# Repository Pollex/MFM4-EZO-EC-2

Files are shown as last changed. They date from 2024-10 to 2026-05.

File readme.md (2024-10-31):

# MFM Atlas Scientific Module x2

This sensor module carries a Atlas-Scientific EZO-EC board and isolates and multiplexes the signal line to two SMA connectors for probes.

This sensor module contains a USB-C port for easier configuration and calibration of the different probes. This also allows the module to be used standalone in an ESD protected environment.

## Hardware

A single MFM V4 has two sensor module slots with about 9mm clearance between slot 1 and 2.

### Parts

Most if not all parts in kicad have a datasheet attached to them. Select the part in the Schematic Editor and press the 'd' key.

## Firmware

To be designed

## Configuration interface

To be designed

# RIOT OS
Clone riot os 2024.07 and apply patch 001

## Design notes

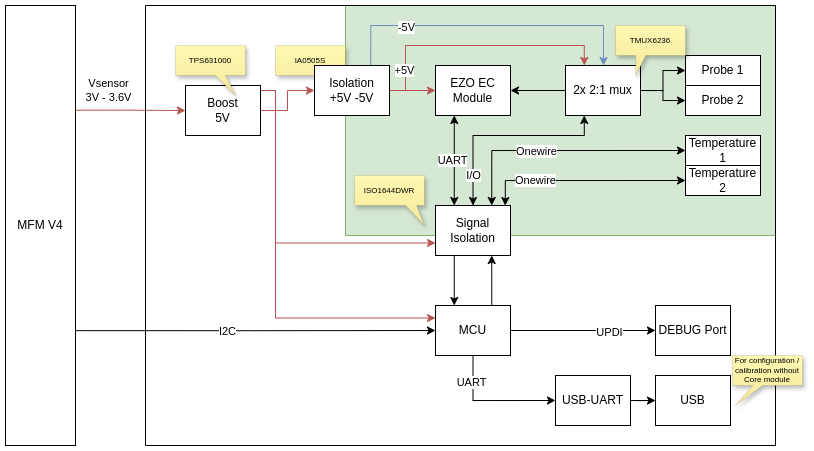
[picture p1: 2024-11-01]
docs/MFM-EC-Diagram.png

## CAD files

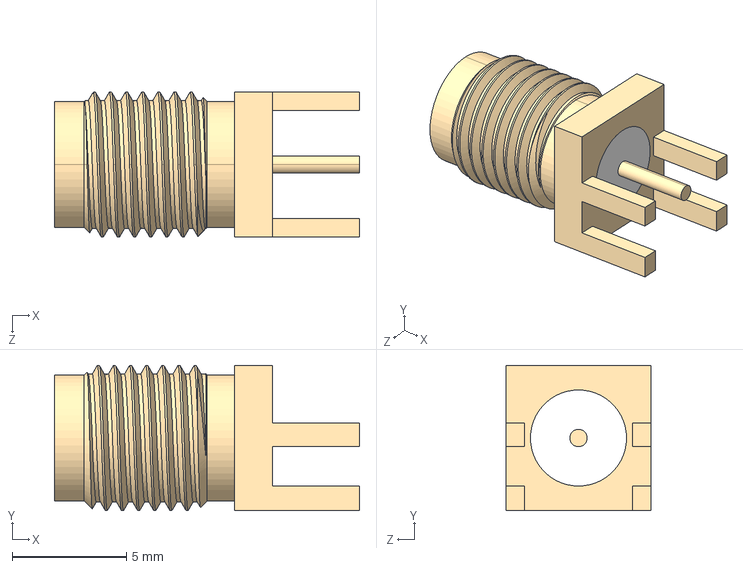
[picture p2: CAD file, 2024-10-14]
hardware/CON-SMA-EDGE-S/CON-SMA-EDGE-S.step
13.3 x 6.35 x 6.35 mm

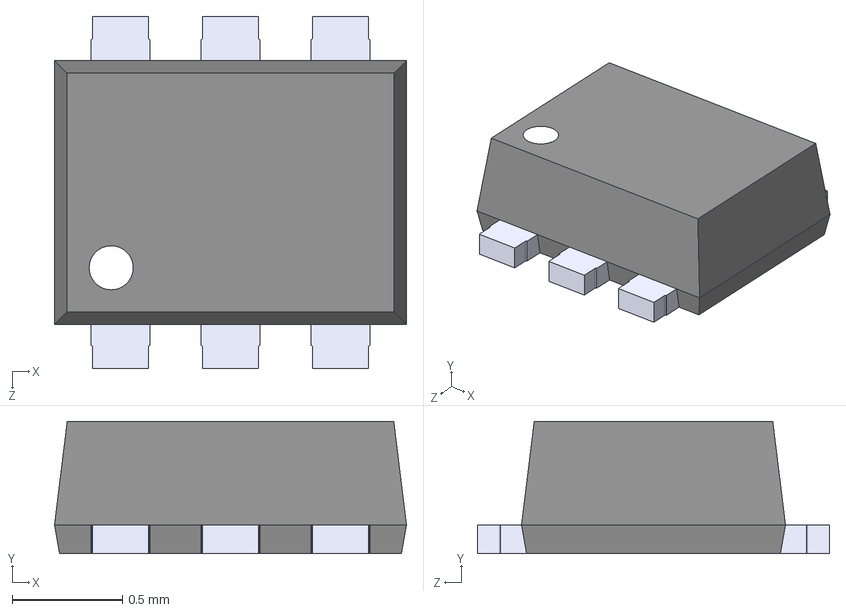
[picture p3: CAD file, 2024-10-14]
hardware/USBLC6-2P6/USBLC6-2P6.step
1.60 x 0.6 x 1.60 mm

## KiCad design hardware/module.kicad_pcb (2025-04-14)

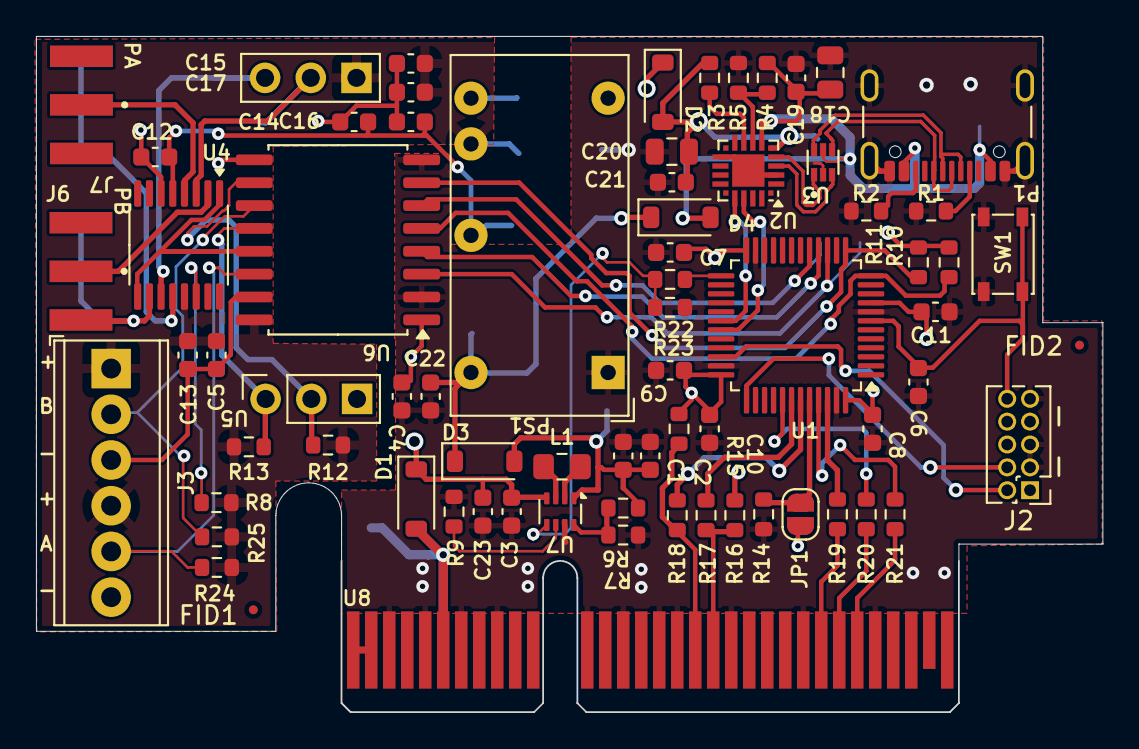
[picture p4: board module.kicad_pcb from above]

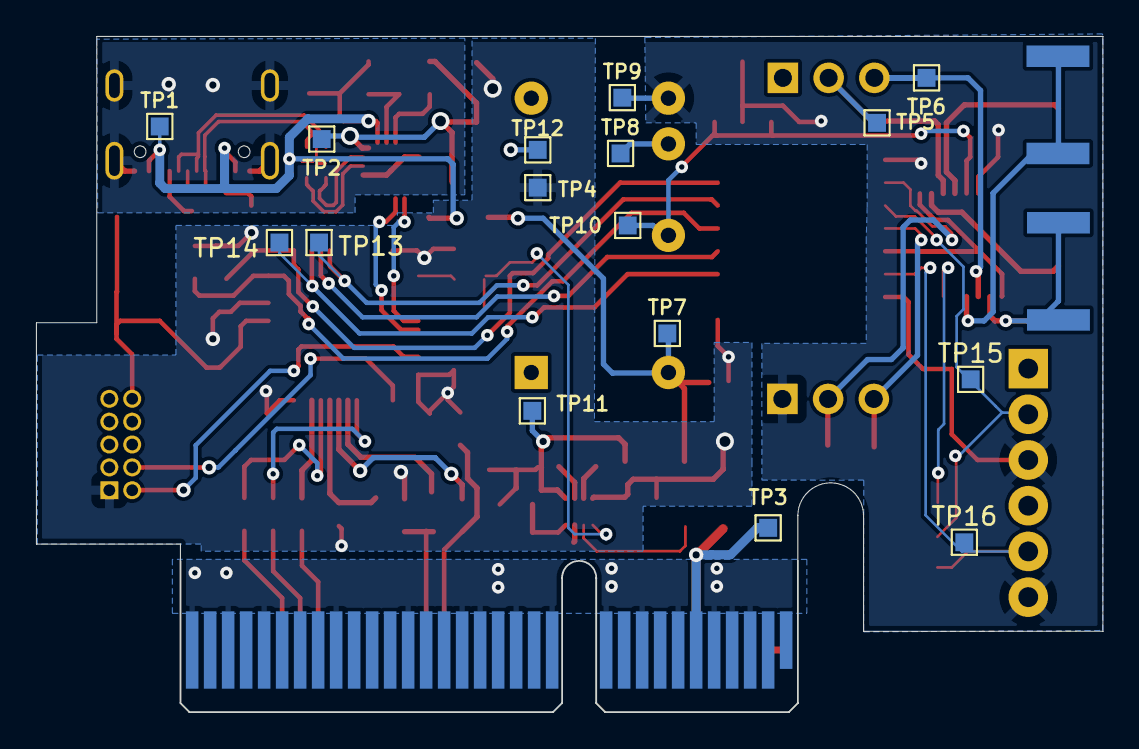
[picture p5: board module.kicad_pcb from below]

Board: 2 copper layers, 59.2 x 37.5 mm, 87 parts (16 on the bottom side), 59 nets.

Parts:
C1, C11, C16, C17, C19, C21: 4u7; C_0603_1608Metric
C2, C22, C23: 10u; C_0603_1608Metric
C3: 22u; C_0603_1608Metric
C4, C5, C6, C7, C8, C9, C10, C12, C13, C14, C15: 100n; C_0603_1608Metric
C18, C20: 47u; C_0805_2012Metric
D1, D2, D3, D4: MBR0520LT1G; D_SOD-123
FID1, FID2: Fiducial; Fiducial_0.5mm_Mask1mm
J2: GPHD-2X05; PinHeader_2x05_P1.27mm_Vertical
J3: 1725698; TerminalBlock_Phoenix_MPT-0,5-6-2.54_1x06_P2.54mm_Horizontal
J6, J7: CON-SMA-EDGE-S; RFSOLUTIONS_CON-SMA-EDGE-S
JP1: BOOT; SolderJumper-2_P1.3mm_Open_RoundedPad1.0x1.5mm
L1: LPWI201208S1R0T; L_0805_2012Metric_Pad1.15x1.40mm_HandSolder
P1: USB4105-GF-A; USB_C_Receptacle_GCT_USB4105-xx-A_16P_TopMnt_Horizontal
PS1: IA0505D; Converter_DCDC_XP_POWER-IAxxxxD_THT
R1, R2, R24, R25: 5k2; R_0603_1608Metric
R3, R14: 1k; R_0603_1608Metric
R4: 22k1; R_0603_1608Metric
R5: 47k5; R_0603_1608Metric
R6: 806k; R_0603_1608Metric
R7: 91k; R_0603_1608Metric
R8, R9, R23: 10k; R_0603_1608Metric
R10, R11, R12, R13: 3k; R_0603_1608Metric
R15, R16: 2K2; R_0603_1608Metric
R17, R18, R19, R20, R21, R22: 0R; R_0603_1608Metric
SW1: PTS810SJG250SMTRLFS; SW_SPST_PTS810
TP1, TP2, TP3, TP4, TP5, TP6, TP7, TP8, TP9, TP10, TP11, TP12, TP13, TP14, TP15, TP16: TestPoint; TestPoint_Pad_1.0x1.0mm
U1: STM32L010C6T6; LQFP-48_7x7mm_P0.5mm
U2: CP2102N-A02-GQFN20; SiliconLabs_QFN-20-1EP_3x3mm_P0.5mm_EP1.8x1.8mm
U3: USBLC6-2P6; SOT50P160X60-6N
U4: TMUX6236PWR; TSSOP-16_4.4x5mm_P0.65mm
U5: EZO-EC™; EZO_EZ
U6: ISO1644DWR; SOIC-16W_7.5x10.3mm_P1.27mm
U7: TPS631000DRLR; SOT-583-8
U8: PCIEx4; BUS_PCIexpress_x4

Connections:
3V3: C3.1, C4.1, C7.1, C8.1, C9.1, C10.1, C11.1, C23.1, D1.1 (K), D2.1 (K), J2.1, JP1.2 (B), R10.2, R11.2, R15.1, R16.1, TP4.1, U1.9 (VDDA), U1.24 (VDD), U1.36 (VDD), U1.48 (VDD), U6.1 (VCC1), U7.4 (Vin)
+5V: C1.1, C2.1, D3.2 (A), R6.2, TP11.1, U7.1 (Vout)
+5V_ISO: C5.1, C13.1, C15.1, C17.1, J3.1, J3.4, PS1.5 (+Vout), R8.2, R12.1, R13.1, R24.2, R25.2, TP8.1, U4.13 (VDD), U5.6 (VCC), U6.16 (VCC2)
-5V_ISO: C12.1, C14.2, C16.2, PS1.4 (-Vout), TP10.1, U4.5 (VSS)
/BOOST_EN: R22.1, R23.1, U7.5 (EN)
/BOOT: JP1.1 (A), R14.2, U1.44 (BOOT0)
/CP_N: U2.5 (D-), U3.1
/CP_P: U2.4 (D+), U3.3
/DQ_TEMP_A: TP14.1, U1.15 (PA5), U6.3 (SDA1)
/DQ_TEMP_A_ISO: J3.5, R24.1, TP16.1, U6.14 (SDA2)
/DQ_TEMP_B: TP13.1, U1.17 (PA7), U6.6 (SCL1)
/DQ_TEMP_B_ISO: J3.2, R25.1, TP15.1, U6.11 (SCL2)
/I2C_SCL: R16.2, R17.1, U8.B19
/I2C_SDA: R15.2, R18.1, U8.B18
/LPUART1_RX: R11.1, U1.13 (PA3), U6.7 (OUT)
/LPUART1_TX: R10.1, U1.12 (PA2), U6.5 (INB)
/MOD_ID1: R19.1, U8.B25
/MOD_ID2: R20.1, U8.B26
/MOD_ID3: R21.1, U8.B27
/NRST: C6.1, J2.10, SW1.2 (B), U1.7 (NRST)
/PRB_SEL: U4.1 (SEL1), U4.9 (SEL2), U6.13 (OUTA)
/PRB_SEL_MCU: U1.16 (PA6), U6.4 (INA)
/SWCLK: J2.4, U1.37 (PA14)
/SWDIO: J2.2, U1.34 (PA13)
/SensorConnector/VBUS: U8.A1, U8.A2, U8.B1, U8.B2
/SensorConnector/VREF: U8.A8, U8.B8
/UART2_RX: U1.31 (PA10), U2.18 (TXD)
/UART2_TX: U1.30 (PA9), U2.17 (RXD)
/USB_N: P1.A7 (D-), P1.B7 (D-), U3.6
/USB_P: P1.A6 (D+), P1.B6 (D+), U3.4
CP2102_3V3: C20.1, C21.1, D2.2 (A), R3.2, TP2.1, U2.6 (VDD)
GND: C1.2, C2.2, C3.2, C4.2, C6.2, C7.2, C8.2, C9.2, C10.2, C11.2, C18.2, C19.2, C20.2, C21.2, C22.2, C23.2, J2.3, J2.5, J2.9, P1.A1 (GND), P1.A12 (GND), P1.B1 (GND), P1.B12 (GND), P1.S1 (SHIELD), PS1.1 (-Vin), R1.2, R2.2, R5.1, R7.1, R9.2, R14.1, R23.2, SW1.1 (A), TP12.1, U1.8 (VSSA), U1.23 (VSS), U1.35 (VSS), U1.47 (VSS), U2.3 (GND), U2.12 (GND), U2.21 (GND), U3.2, U6.2 (GND1), U6.8 (GND1), U7.7 (GND), U8.A3, U8.A4, U8.A5, U8.A7, U8.A9, U8.A11, U8.A12, U8.A14, U8.A16, U8.A17, U8.A18, U8.A19, U8.A20, U8.A24, U8.A26, U8.A28, U8.A30, U8.A32, U8.B3, U8.B5, U8.B7, U8.B9, U8.B12, U8.B14, U8.B16, U8.B17, U8.B20, U8.B24, U8.B28
GND_ISO: C5.2, C12.2, C13.2, C14.1, C15.2, C16.1, C17.2, J3.3, J3.6, PS1.6 (0V), TP9.1, U4.6 (GND), U5.3 (GND), U6.9 (GND2), U6.15 (GND2)
unnamed: C22.1, D3.1 (K), D4.1 (K), PS1.3 (+Vin), TP7.1
unnamed: P1.A5 (CC), R1.1
unnamed: P1.B5 (VCONN), R2.1
unnamed: R20.2, U1.41 (PB5)
unnamed: R17.2, U1.42 (PB6)
unnamed: R18.2, U1.43 (PB7)
unnamed: R21.2, U1.45 (PB8)
unnamed: R19.2, U1.46 (PB9)
unnamed: R22.2, U1.25 (PB12)
unnamed: R4.1, R5.2, U2.8 (VBUS)
unnamed: R3.1, U2.9 (~RST)
unnamed: TP5.1, U4.3 (D1), U5.5 (PRB)
unnamed: TP6.1, U4.11 (D2), U5.4 (PRB)
unnamed: R8.1, U4.14 (EN)
unnamed: J6.1, U4.2 (S1A)
unnamed: J7.1, U4.4 (S1B)
unnamed: J6.G1, J6.G2, J6.G3, J6.G4, U4.10 (S2A)
unnamed: J7.G1, J7.G2, J7.G3, J7.G4, U4.12 (S2B)
unnamed: R13.2, U5.1 (RX/SCL), U6.12 (OUTB)
unnamed: R12.2, U5.2 (TX/SDA), U6.10 (INC)
unnamed: R6.1, R7.2, U7.8 (FB)
unnamed: L1.1, U7.3 (LX1)
unnamed: L1.2, U7.2 (LX2)
unnamed: R9.1, U7.6 (MODE)
USB_VBUS: C18.1, C19.1, D4.2 (A), P1.A4 (VBUS), P1.A9 (VBUS), P1.B4 (VBUS), P1.B9 (VBUS), R4.2, TP1.1, U2.7 (VREGIN), U3.5
VSensor: D1.2 (A), TP3.1, U8.A6, U8.B6

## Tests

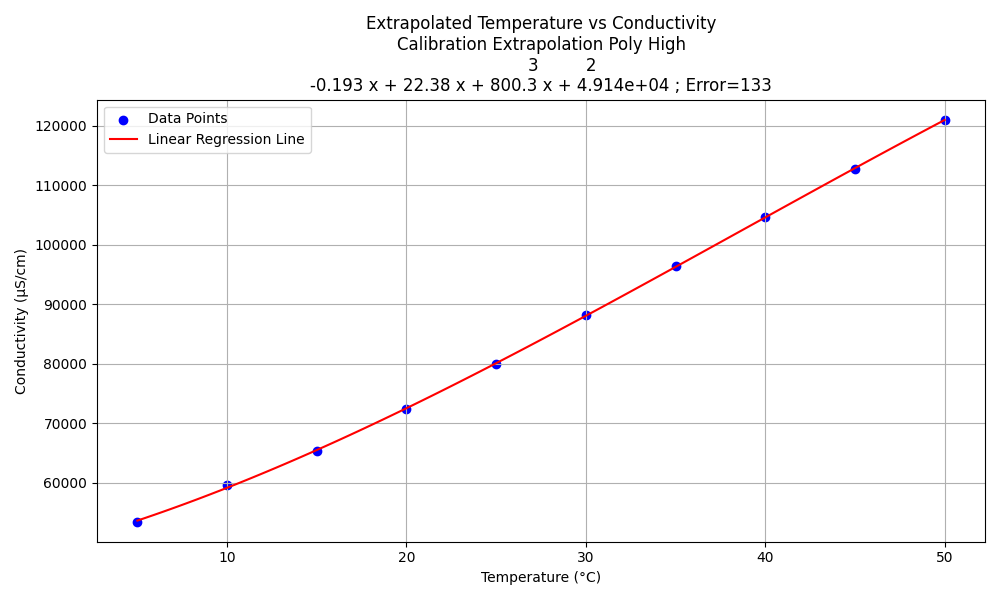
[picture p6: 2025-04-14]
docs/calibration_extrapolation_poly_high.png

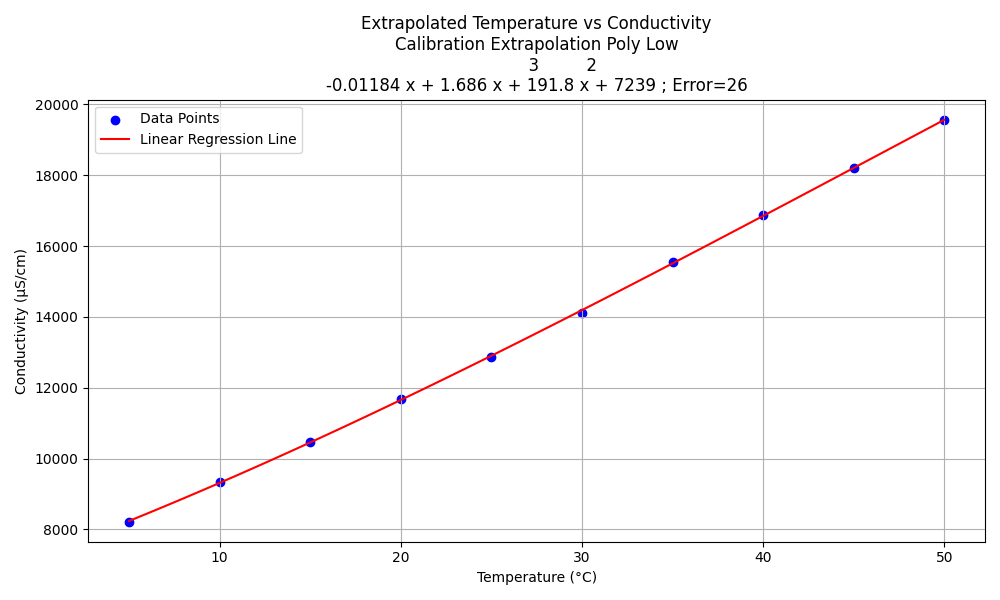
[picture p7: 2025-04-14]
docs/calibration_extrapolation_poly_low.png

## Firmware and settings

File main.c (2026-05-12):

#include "board.h"
#include "config.h"
#include "ds18_local.h"
#include "ezoec.h"
#include "mfm_comm.h"
#include "msg.h"
#include "periph/cpu_gpio.h"
#include "periph/eeprom.h"
#include "periph/gpio.h"
#include "periph/uart.h"
#include "irq.h"
#include "sched.h"
#include "shell.h"
#include "stm32l010x6.h"
#include "thread.h"
#include <inttypes.h>
#include <stddef.h>
#include <stdint.h>
#include <stdio.h>
#include <stdlib.h>
#include <sys/unistd.h>
#include <ztimer.h>
#define ENABLE_DEBUG 0
#include <debug.h>

#ifndef FW_VERSION
#define FW_VERSION "NO_VER"
#endif /* ifndef FW_VERSION */

// ==================================
// Variables
// ==================================
static ezoec_t ec                     = {0};
static ds18_t t1                      = {0};
static ds18_t t2                      = {0};
static const ezoec_params_t ec_params = {
    .baud_rate = 115200,
    .uart      = UART_DEV(1),
};
static const ds18_params_t t1_params = {
    .pin      = DQ_A_PIN,
    .out_mode = GPIO_OD_PU,
};
static const ds18_params_t t2_params = {
    .pin      = DQ_B_PIN,
    .out_mode = GPIO_OD_PU,
};

typedef enum {
    PROBE_A,
    PROBE_B,
} probe_t;

typedef struct {
    uint32_t conductivity_a;
    uint32_t conductivity_b;
    int16_t temperature_b;
    int16_t temperature_a;
} measurement_t;

// ==================================
// Flags
// ==================================
// measurement_t measurement = {0};
volatile struct __attribute__((packed)) {
    uint32_t conductivity_a;
    uint32_t conductivity_b;
    int16_t temperature_b;
    int16_t temperature_a;
} wire_measurement                  = {0};
static kernel_pid_t main_thread_pid = 1;

// ==================================
// Errors (bit flags for multiple failures)
// ==================================
typedef enum APP_ERROR {
    ERR_NONE           = 0,
    ERR_SENSOR_INIT    = (1 << 0), // Sensor initialization failed
    ERR_TEMP_A_TRIGGER = (1 << 1), // Temperature A trigger failed
    ERR_TEMP_B_TRIGGER = (1 << 2), // Temperature B trigger failed
    ERR_CONDUCTIVITY_A = (1 << 3), // Conductivity probe A failed
    ERR_CONDUCTIVITY_B = (1 << 4), // Conductivity probe B failed
    ERR_TEMP_A_READ    = (1 << 5), // Temperature A read failed
    ERR_TEMP_B_READ    = (1 << 6), // Temperature B read failed
} APP_ERROR;

// ==================================
// MSG Commands
// ==================================
typedef enum APP_MSG {
    MSG_UNKNOWN,
    MSG_MFR_INIT,
    MSG_DO_MEASURE,
    MSG_CLEAR_BOOT_MAGIC,
} APP_MSG;

// ==================================
// MFM Communications
// ==================================

static int mfm_comm_sensor_init(void *arg);
static int mfm_comm_perform_measurement(void *arg);
static const mfm_comm_params_t mfm_comm_params = {
    .firmware_version       = FW_VERSION,
    .module_type            = 0xFF,
    .measurement_time       = 15000,
    .sensor_count           = 1,
    .sensor_init_fn         = &mfm_comm_sensor_init,
    .perform_measurement_fn = &mfm_comm_perform_measurement,
};
static mfm_comm_t mfm_comm;

/**
 * @brief Called from an interrupt when the MFM tasks us to do a mfr sensor
 * init.
 *
 * @param arg
 * @return 0 on success, negative on error.
 */
static int mfm_comm_sensor_init(void *arg) {
    (void)arg;

    msg_t msg;

    msg.type = MSG_MFR_INIT;
    if (msg_try_send(&msg, main_thread_pid) != 1) {
        DEBUG("mfm_comm sensor init msg not sent.");
        return -1; // Action was not sent.
    };

    return 0;
}

/**
 * @brief Called from an interrupt when the MFM tasks us to start a measurement.
 *
 * @param arg
 * @return 0 on success, negative on error.
 */
static int mfm_comm_perform_measurement(void *arg) {
    (void)arg;

    msg_t msg;

    msg.type = MSG_DO_MEASURE;
    if (msg_try_send(&msg, main_thread_pid) != 1) {
        DEBUG("mfm_comm perform msg not sent.");
        return -1; // Action was not sent.
    };

    return 0;
}

// ==================================
// Config
// ==================================

eeprom_config_t eeprom_config = {0};

int config_has_calibration(uint8_t probe) {
    if (probe == PROBE_A)
        return (eeprom_config.flags & CFG_FLAG_A_CALIBRATED) > 0;
    if (probe == PROBE_B)
        return (eeprom_config.flags & CFG_FLAG_B_CALIBRATED) > 0;
    return -EINVAL;
}

int config_init(void) {
    eeprom_read(0, &eeprom_config, sizeof(eeprom_config));
    if (strcmp(eeprom_config.magic, CFG_MAGIC_HEADER) != 0) {
        puts("!!! NOTICE: corrupted config, resetting");
        config_clear();
        config_persist();
    }
    // if (!config_has_calibration(PROBE_A)) {
    //     puts("!!! NOTICE: Probe A is not calibrated");
    // }
    // if (!config_has_calibration(PROBE_B)) {
    //     puts("!!! NOTICE: Probe B is not calibrated");
    // }
    return 0;
}

int config_clear(void) {
    memset(&eeprom_config, 0x00, sizeof(eeprom_config));
    memcpy(&eeprom_config.magic, CFG_MAGIC_HEADER, sizeof(CFG_MAGIC_HEADER));
    return 0;
}

int config_persist(void) { return eeprom_write(0, &eeprom_config, sizeof(eeprom_config)); }

// ==================================
// Functions
// ==================================

int sensors_init(void) {
    int result = ezoec_init(&ec, &ec_params);
    if (result < 0) {
        printf("EZOEC Initialization error: %d\n", result);
        return -1;
    }

    result = ds18_init(&t1, &t1_params);
    if (result < 0) {
        printf("DS18B20 A Initialization error: %d\n", result);
        return -1;
    }

    result = ds18_init(&t2, &t2_params);
    if (result < 0) {
        printf("DS18B20 B Initialization error: %d\n", result);
        return -1;
    }

    return 0;
}

void sensors_enable(void) {
    gpio_init(BOOST_EN_PIN, GPIO_OUT);
    gpio_set(BOOST_EN_PIN);
}
void sensors_disable(void) {
    gpio_clear(BOOST_EN_PIN);
    gpio_init(BOOST_EN_PIN, GPIO_IN);
}

int sensors_trigger_temperature(probe_t probe) {
    ds18_t *t = &t1;
    if (probe == PROBE_B) {
        t = &t2;
    }
    int result = ds18_trigger(t);
    if (result < 0) {
        return result;
    }
    return 0;
}
int sensors_get_temperature(probe_t probe, int16_t *out) {
    ds18_t *t = &t1;
    if (probe == PROBE_B) {
        t = &t2;
    }
    *out       = 0;
    int result = ds18_read(t, out);
    if (result < 0) {
        return result;
    }
    return 0;
}

static int switch_probe(uint8_t index) {
    gpio_write(PRB_SEL_PIN, index);
    return 0;
}

int sensors_get_conductivity(probe_t probe, uint32_t *out) {
    int result;
    *out = 0;

    // Switch probe
    switch_probe(probe);

    // Set probe K
    uint8_t k = eeprom_config.k_values[probe];
    if (k > 0) {
        result = ezoec_set_k(&ec, k);
        if (result < 0) {
            return result;
        }
    } else {
        printf("Warning: probe %c has no K value set\n", probe == PROBE_A ? 'A' : 'B');
    }

    // Load calibration into ezoec
    if (config_has_calibration(probe)) {
        result = ezoec_cal_import(&ec, &eeprom_config.calibration[probe]);
        if (result < 0) {
            return result;
        }
        // TODO: Add justification for 1s delay.
        ztimer_sleep(ZTIMER_MSEC, 1000);
    } else {
        printf("Warning: probe %c has no calibration\n", probe == PROBE_A ? 'A' : 'B');
    }

    result = ezoec_measure(&ec, out);
    if (result < 0) {
        *out = 0;
        return result;
    }

    return 0;
}

static int perform_measurement(measurement_t *m, uint8_t *error_flags) {
    *error_flags = ERR_NONE;
    memset(m, 0, sizeof(*m));

    sensors_enable();
    ztimer_sleep(ZTIMER_MSEC, 1000);

    int result = sensors_init();
    if (result < 0) {
        DEBUG("ERR(%d) sensors init\n", result);
        sensors_disable();
        *error_flags |= ERR_SENSOR_INIT;
        return result;
    }

    // Trigger temperature conversions first so they run in parallel with the
    // (slower) EC measurement.
    if (config_has_calibration(PROBE_A)) {
        result = sensors_trigger_temperature(PROBE_A);
        if (result < 0) {
            DEBUG("ERR(%d) trigger temp A\n", result);
            *error_flags |= ERR_TEMP_A_TRIGGER;
        }
    }
    if (config_has_calibration(PROBE_B)) {
        result = sensors_trigger_temperature(PROBE_B);
        if (result < 0) {
            DEBUG("ERR(%d) trigger temp B\n", result);
            *error_flags |= ERR_TEMP_B_TRIGGER;
        }
    }

    if (config_has_calibration(PROBE_A)) {
        result = sensors_get_conductivity(PROBE_A, &m->conductivity_a);
        if (result < 0) {
            DEBUG("ERR(%d) conduc A\n", result);
            m->conductivity_a = 0;
            *error_flags |= ERR_CONDUCTIVITY_A;
        }
    }
    if (config_has_calibration(PROBE_B)) {
        result = sensors_get_conductivity(PROBE_B, &m->conductivity_b);
        if (result < 0) {
            DEBUG("ERR(%d) conduc B\n", result);
            m->conductivity_b = 0;
            *error_flags |= ERR_CONDUCTIVITY_B;
        }
    }

    if (config_has_calibration(PROBE_A)) {
        result = sensors_get_temperature(PROBE_A, &m->temperature_a);
        if (result < 0) {
            DEBUG("ERR(%d) get temp A\n", result);
            m->temperature_a = 0;
            *error_flags |= ERR_TEMP_A_READ;
        }
    }
    if (config_has_calibration(PROBE_B)) {
        result = sensors_get_temperature(PROBE_B, &m->temperature_b);
        if (result < 0) {
            DEBUG("ERR(%d) get temp B\n", result);
            m->temperature_b = 0;
            *error_flags |= ERR_TEMP_B_READ;
        }
    }

    sensors_disable();
    return 0;
}

// ==================================
// Shell commands
// ==================================

static char *_int_to_string(uint32_t k, uint8_t precision, char *buf) {
    enum { buf_len = 20 };
    static char internal_buf[buf_len + 1] = {0};
    if (buf == NULL)
        buf = internal_buf;
    char *ptr = &buf[buf_len - 1];

    if (k == 0) {
        *ptr-- = '0';
        return ptr + 1;
    }

    int decimals = 0;
    while (k > 0) {
        char decimal = 0x30 + (k % 10);
        k /= 10;

        *ptr-- = decimal;
        if (++decimals == precision) {
            *ptr-- = '.';
            if (k == 0)
                *ptr-- = '0';
        }
    }
    return ptr + 1;
}

#define STABLE_READING_SAMPLES 12
static int wait_for_stable_readings(uint32_t timeout, uint32_t tolerance_uS) {
    uint32_t readings[STABLE_READING_SAMPLES] = {0};
    uint8_t total_readings                    = 0;

    uint32_t start = ztimer_now(ZTIMER_MSEC);
    int result     = 0;
    for (;;) {
        //
        // Check if we've reached timeout limit
        if (ztimer_now(ZTIMER_MSEC) - start > timeout) {
            return -ETIMEDOUT;
        }

        //
        // Get a new measurement
        result = ezoec_measure(&ec, &readings[total_readings % STABLE_READING_SAMPLES]);
        if (result < 0) {
            return result; // Return the error code
        }
        // Convert nS to uS
        readings[total_readings % STABLE_READING_SAMPLES] /= 1000;
        total_readings++;

        // Only check std with X samples
        printf("Collecting samples: %2d \t-->\t%ld uS\n", total_readings,
               readings[(total_readings - 1) % STABLE_READING_SAMPLES]);
        if (total_readings < STABLE_READING_SAMPLES) {
            continue;
        }

        //
        // Check spread (max - min) across the buffered window.
        uint32_t min = readings[0];
        uint32_t max = readings[0];
        for (int i = 1; i < STABLE_READING_SAMPLES; i++) {
            if (readings[i] < min)
                min = readings[i];
            if (readings[i] > max)
                max = readings[i];
        }
        uint32_t spread = max - min;

        printf("Min: %" PRIu32 "\tMax: %" PRIu32 "\tSpread: %" PRIu32 " uS\tTolerance: %" PRIu32 " uS\n", min, max,
               spread, tolerance_uS);

        if (spread <= tolerance_uS) {
            return 0; // Stable
        }
    }

    return 0; // This line is unreachable due to the loop
}

static void _wait_for_enter(void) {
    while (getchar() != 0x0A)
        ;
}

static int32_t _read_int(uint8_t precision) {
    enum { rx_buffer_size = 20 };
    static char rx_buffer[rx_buffer_size] = {0};

    char *ptr_start = rx_buffer;
    char *ptr_end   = ptr_start; // will be incremented during reading
    char *ptr       = ptr_start;

    uint8_t c = 0;
    for (;;) {
        c = getchar();
        if (c == 0x0A) {
            break;
        }
        *ptr_end++ = c;
        if ((ptr_end - ptr_start) >= rx_buffer_size) {
            break;
        }
    }
    if (c != 0x0A) {
        return -ENOBUFS;
    }

    // Convert to int
    int32_t value    = 0;
    uint8_t decimals = 0;
    while (ptr < ptr_end) {
        if (*ptr == '.') {
            decimals = ptr_end - ptr - 1;
            ptr++;
            continue;
        }

        value *= 10;
        value += (*ptr - 0x30);
        ptr++;
    }
    // Correct for potential missing decimals
    for (int x = precision - decimals; x > 0; x--) {
        value *= 10;
    }

    return value;
}

static int32_t _read_mS(void) { return _read_int(3); }
static int32_t _read_kvalue(void) { return _read_int(1); }

#define CAL_TOLERANCE_DRY_uS  1000
#define CAL_TOLERANCE_LOW_uS  1000
#define CAL_TOLERANCE_HIGH_uS 1000
int cmd_provision(int argc, char **argv) {
    int calibrate_a = 1;
    int calibrate_b = 1;

    if (argc >= 2) {
        if (argv[1][0] == 'A' || argv[1][0] == 'a') {
            calibrate_b = 0;
        } else if (argv[1][0] == 'B' || argv[1][0] == 'b') {
            calibrate_a = 0;
        } else {
            printf("Usage: %s [A|B]\n", argv[0]);
            return -1;
        }
    }

    puts("1. Fixing EZOEC configuration");
    ezoec_params_t params = {
        .baud_rate = 9600,
        .uart      = UART_DEV(1),
    };
    int result = ezoec_init(&ec, &params);
    if (result < 0) {
        printf("Could not initialize EZOEC on factory settings, perhaps its "
               "already fixed: %d\n",
               result);
    } else {
        ezoec_set_baud(&ec, 115200);
        puts("Fixed ezoec baudrate");
    }
    result = ezoec_init(&ec, &ec_params);
    if (result < 0) {
        printf("Could not initialize EZOEC after fix, aborting: %d\n", result);
        return result;
    }
    // Factory reset (does not affect baud)
    result = ezoec_factory(&ec);
    if (result < 0) {
        printf("Could not factory reset EZOEC: %d\n", result);
        return result;
    }
    puts("Factory reset EZOEC");
    // Disable continuous mode
    result = ezoec_cmd(&ec, 0, NULL, 0, "C,0");
    if (result < 0) {
        printf("Could not disable continuous mode: %d\n", result);
        return result;
    }
    puts("Disabled EZOEC continuous reading");
    // Disable LED
    result = ezoec_cmd(&ec, 0, NULL, 0, "L,0");
    if (result < 0) {
        printf("Could not disable LED: %d\n", result);
        return result;
    }
    puts("Disabled EZOEC LED");

    int k_value;
    if (calibrate_a) {
    retry_ka:
        puts("2. K-Value of probe A: ");
        k_value = _read_kvalue();
        if (k_value < 0) {
            printf("error(%d), try again\n", k_value);
            goto retry_ka;
        }
        eeprom_config.k_values[0] = k_value;
        printf("Got %s\n", _int_to_string(k_value, 1, NULL));
    }

    if (calibrate_b) {
    retry_kb:
        puts("3. K-Value of probe B: ");
        k_value = _read_kvalue();
        if (k_value < 0) {
            printf("error(%d), try again\n", k_value);
            goto retry_kb;
        }
        eeprom_config.k_values[1] = k_value;
        printf("Got %s\n", _int_to_string(k_value, 1, NULL));
    }

    for (int probe = 0; probe < 2; probe++) {
        if (probe == PROBE_A && !calibrate_a)
            continue;
        if (probe == PROBE_B && !calibrate_b)
            continue;
        printf("Switching to probe: %c (K: %s)\n", probe == 0 ? 'A' : 'B',
               _int_to_string(eeprom_config.k_values[probe], 1, NULL));
        switch_probe(probe);
        result = ezoec_set_k(&ec, eeprom_config.k_values[probe]);
        if (result < 0) {
            printf("There are issues setting the K value (error %d).\n", result);
            return result;
        }
    retry_dry:
        printf("4%c.1: Dry calibration. Make sure the probe is dry and "
               "press "
               "enter...\n",
               probe == 0 ? 'A' : 'B');
        _wait_for_enter();
        puts("Waiting for readings to stabalize...");
        result = wait_for_stable_readings(10000, CAL_TOLERANCE_DRY_uS);
        if (result < 0) {
            printf("There are issues getting a stable reading (error %d). "
                   "Check connections and dryness.\n",
                   result);
            goto retry_dry;
        }
        result = ezoec_cal_dry(&ec);
        if (result < 0) {
            printf("Could not perform calibration: %d\n", result);
            return result;
        }

    retry_low:
        printf("5%c.1: Low calibration. Put probe in low mS solution.\n", probe == 0 ? 'A' : 'B');
        puts("Solution concentration in mS: ");
        // We ask the user for mS with max 3 decimals so store as uS
        uint32_t uS = _read_mS();
        printf("Calibrating for: %s mS\n", _int_to_string(uS, 3, NULL));
        puts("Waiting for readings to stabalize...");
        result = wait_for_stable_readings(10000, CAL_TOLERANCE_LOW_uS);
        if (result < 0) {
            printf("There are issues getting a stable reading (error %d). "
                   "Check for trapped air.\n",
                   result);
            goto retry_low;
        }
        result = ezoec_cal_low(&ec, uS);
        if (result < 0) {
            printf("Could not perform calibration: %d\n", result);
            return result;
        }

    retry_high:
        printf("6%c.1: High calibration. Put probe in high uS solution.\n", probe == 0 ? 'A' : 'B');
        puts("Solution concentration in mS: ");
        uS = _read_mS();
        printf("Calibrating for: %s mS\n", _int_to_string(uS, 3, NULL));
        puts("Waiting for readings to stabalize...");
        result = wait_for_stable_readings(10000, CAL_TOLERANCE_HIGH_uS);
        if (result < 0) {
            printf("There are issues getting a stable reading (error %d). "
                   "Check for trapped air.\n",
                   result);
            goto retry_high;
        }
        result = ezoec_cal_high(&ec, uS);
        if (result < 0) {
            printf("Could not perform calibration: %d\n", result);
            return result;
        }

        printf("7%c.1: Calibration done, exporting calibration values...", probe == 0 ? 'A' : 'B');
        result = ezoec_cal_export(&ec, &eeprom_config.calibration[probe]);
        if (result < 0) {
            printf("Could not export calibration: %d\n", result);
            return result;
        }
        eeprom_config.flags |= CFG_FLAG_A_CALIBRATED << probe;
    }

    puts("7. Provisioning is now done, press enter to save...");
    _wait_for_enter();
    config_persist();
    puts("Saved, module is ready for use. If a probe is swapped, run this "
         "procedure again!");

    return 0;
}

int cmd_ec_cmd(int argc, char **argv) {
    (void)argc;
    (void)argv;

    if (argc < 2) {
        printf("Usage: %s <command>\n", argv[0]);
        return -1;
    }

    ezoec_writeline(&ec, argv[1]);
    char buf[RX_MAX_LINE_LEN] = {0};
    int result                = 0;
    for (;;) {
        result = ezoec_readline(&ec, buf, RX_MAX_LINE_LEN, 1000);
        if (result < 0)
            break;
        buf[result] = 0;
        printf("<<< %s\n", buf);
    }

    return 0;
}
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
int main(void) {
    // gpio_init(PIN_TEST, GPIO_OUT);
    // gpio_set(PIN_TEST);

    gpio_init(PRB_SEL_PIN, GPIO_OUT);
    gpio_init(BOOST_EN_PIN, GPIO_IN);

    main_thread_pid = thread_getpid();
    msg_init_queue(_msg_queue, 8);

    // Setup I2C with master.
    mfm_comm_init(&mfm_comm, mfm_comm_params);

    config_init();

    printf("FWVER: %s\n", FW_VERSION);

    // Duration: 0.038 ms
    if (should_boot_shell())
        return main_shell();

    static msg_t msg = {0};
    for (;;) {
        DEBUG("Wait msg\n");
        msg_receive(&msg);
        switch (msg.type) {
        case MSG_MFR_INIT:
            DEBUG("Sensor init\n");
            mfm_comm_sensor_init_finish(&mfm_comm);
            break;
        case MSG_DO_MEASURE: {
            DEBUG("Sensor measure\n");

            measurement_t measurement = {0};
            uint8_t error_flags       = ERR_NONE;

            perform_measurement(&measurement, &error_flags);

            if (error_flags & ERR_SENSOR_INIT) {
                mfm_comm_measurement_error(&mfm_comm, ERR_SENSOR_INIT);
                break;
            }
            if (error_flags != ERR_NONE) {
                printf("ERR: %02X\n", error_flags);
                mfm_comm_measurement_error(&mfm_comm, error_flags);
            }

            wire_measurement.conductivity_a = measurement.conductivity_a;
            wire_measurement.conductivity_b = measurement.conductivity_b;
            wire_measurement.temperature_a  = measurement.temperature_a;
            wire_measurement.temperature_b  = measurement.temperature_b;

            mfm_comm_measurement_finish(&mfm_comm, (void *)&wire_measurement, sizeof(wire_measurement));
        } break;
        case MSG_CLEAR_BOOT_MAGIC:
            PWR->CR |= PWR_CR_DBP;
            RTC->BKP0R = 0;
            break;
        }
    }
    return 0;
}

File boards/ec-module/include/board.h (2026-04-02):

#ifndef BOARD_H
#define BOARD_H

#ifdef __cplusplus
extern "C" {
#endif

#define CONFIG_ZTIMER_USEC_WIDTH        (16)
#define CONFIG_ZTIMER_USEC_ADJUST_SET   20
#define CONFIG_ZTIMER_USEC_ADJUST_SLEEP 27

#define LPUART_TX_PIN GPIO_PIN(PORT_A, 2)
#define LPUART_RX_PIN GPIO_PIN(PORT_A, 3)

#define PRB_SEL_PIN GPIO_PIN(PORT_A, 6)
#define DQ_A_PIN    GPIO_PIN(PORT_A, 5)
#define DQ_B_PIN    GPIO_PIN(PORT_A, 7)

#define BOOST_EN_PIN GPIO_PIN(PORT_B, 12)

#define MFM_COMM_ID1_PIN GPIO_PIN(PORT_B, 9)
#define MFM_COMM_ID2_PIN GPIO_PIN(PORT_B, 5)
#define MFM_COMM_ID3_PIN GPIO_PIN(PORT_B, 8)

#ifdef __cplusplus
}
#endif

#endif /* BOARD_H */
/** @} */

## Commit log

2024-10-14 Update PCB module design
    [CON-SMA-EDGE-S.step, USBLC6-2P6.step, module.kicad_pcb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]
2024-10-16 feat: calibration import export
2024-10-28 Feat: calibration stabilize before continue
    [board.h, ezoec.c, main.c]
2024-10-31 implement i2c slave, commands, measurements and provisioning procedure
2024-10-31 Fix: i2c use msg to main thread
    [main.c]
2024-10-31 feat: disable ezoec led during provisioning
2024-11-01 Fix: i2c addr calculation, update diagram
    [main.c]
2025-04-14 feat: new shell commands chore: remove saul pins chore: add compile time FW_VERSION docs: add calibration interpolated graphs
    [module.kicad_pcb, module.kicad_sch, sensor_connector.kicad_sch]
2025-06-30 fix(i2c): not initializing correctly in slot 2 This commit also fixes the Time-To-Ready of I2C from 500ms to <1ms.
    [main.c]
2025-06-30 chore: update board config for newer RIOT
2025-08-22 fix: incorrect i2c speed
2025-08-22 feat: riot: i2c slave
2026-03-09 chore: fix zero init, increase measurement_time
    [main.c]
2026-03-09 feat: add mfm comm errors
    [main.c]
2026-03-13 refactor: improve threading and error handling in ezoec driver
    Replace polling-based ringbuffer with thread-safe ring buffer (tsrb) and
    use thread flags for efficient UART rx synchronization. Add mutex protection
    for readline operations and improve error propagation in mfm_comm and sensor
    initialization paths. Implement set_k shell command and increase message
    queue capacity for better reliability.
    [ezoec.c, main.c, mfm_comm.c]
2026-03-16 fix: tsrf buf ^2, out = 0 on error
    [ezoec.c]
2026-03-17 feat: conditional probe calib/usage
2026-04-14 fix: enforce 750ms for ds18b20 refactor: merge to main.c
    [ezoec.c, main.c]
2026-05-12 fix(mfm_comm): return app_error byte on second read_error_status
    When MFM_COMM_ERR_APP is asserted, the protocol expects the host to read
    once for the generic error byte and a second time for the application-
    specific payload. The second read was returning comm->error again, so
    the MFM master never saw the actual per-probe error bitmap assembled in
    main.c (ERR_TEMP_A_TRIGGER, ERR_CONDUCTIVITY_A, etc.).
    [mfm_comm.c]
2026-05-12 fix(ezoec): _int_to_string handles k=0 and all precisions
    The helper previously skipped the digit-writing loop when k==0, returning
    a pointer to the static buffer's NUL terminator. Any caller invoking
    ezoec_set_k(0) would have sent "K,\r" and received *ER from the EZO.
    Also fixes precision > 1 with k < 10^(precision-1): the loop only inserted
    the decimal point when reaching `precision` digits of input, so values
    like (k=1, precision=3) returned "1" instead of "0.001". The do-while
    now pads with leading zeros until enough fractional digits exist.
    Adds tests/test_int_to_string.c — host-side test (cc + run, no RIOT
    needed) that covers k=0 across precisions, integer-only output, and the
    K-va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
    [ezoec.c]
2026-05-12 refactor(provisioning): use min-max spread instead of variance for stability
    The variance computation mixed signed and unsigned types and squared
    deviations into a uint32_t, which would overflow for high-K-probe
    readings near saline-range conductivities (e.g. 100k uS² already
    overflows int32 squared math).
    Replace with a straightforward min-max spread across the rolling window
    and compare against the tolerance directly. Simpler, intuitive, and
    overflow-free. Uses PRIu32 format macros to follow RIOT convention.
    [main.c]
2026-05-12 fix(ezoec): return -ENODEV when init detects a non-EC device
    ezoec_init previously returned the positive byte count from the version
    read on both "response too short" and "device is not EC" branches.
    Callers (e.g. sensors_init in main.c) treat any negative return as
    failure, so a non-EC EZO module on the UART would silently look like
    a healthy init. Return -ENODEV in both cases.
    [ezoec.c]
2026-05-12 fix(ezoec): bounds-check cal_export against calibration array
    The Export loop memcpy'd into cal->line[line] before checking the
    EZOEC_CALIBRATION_MAX_LINES bound. If the EZO ever returned more lines
    than expected before *DONE (or the constants drift), the trailing
    iteration writes past the array. Also clamp the per-line memcpy size
    to EZOEC_CALIBRATION_LINE_LENGTH so a long response can't spill into
    the next slot.
    [ezoec.c]
2026-05-12 fix(ezoec): guard vsnprintf return in writeline/cmd
    vsnprintf returns the number of bytes that would be written, not the
    number actually written. If a format ever truncates (or returns
    negative on encoding error), the next line `txbuf[len++] = '\r'` writes
    out of bounds into BSS, corrupting adjacent statics. Bail with
    -EOVERFLOW on both overflow and encoding error.
    [ezoec.c]
2026-05-12 fix(ezoec): harden ezoec_measure parser against unexpected output
    The parser blindly added (*ptr - '0') to a uint32_t accumulator. A
    comma — as appears in multi-field output like "100,54" when TDS/SAL/SG
    is enabled — yields -4 and wraps the accumulator into garbage. Now
    stop at the first non-digit/non-dot character, reject double-dot input,
    and require at least one digit. Behaviour for EC-only output ("1413"
    or "1.413") is unchanged.
    [ezoec.c]
2026-05-12 fix(ezoec): pass caller buffer size into ezoec_cmd
    Previously ezoec_cmd hardcoded RX_MAX_LINE_LEN (42 bytes) as the read
    length regardless of the caller's actual buffer. Callers with smaller
    buffers — version[15] in ezoec_init, rxBuffer[13] in ezoec_cal_export
    — could be overflowed by a long EZO response, corrupting the stack.
    Add an out_len parameter and propagate it through ezoec_readline.
    All call sites pass sizeof(buf) for the buffered cases or 0 for the
    NULL-out case.
    [ezoec.c, main.c]
2026-05-12 refactor: consolidate measurement into shared perform_measurement()
    Extract the EC + temperature measurement flow into a single helper used
    by both the shell `measure` command and the I2C MSG_DO_MEASURE handler,
    so they no longer drift. The shell path now initializes sensors and
    respects per-probe calibration gating; the I2C path drops its 850 ms
    blocking wait by triggering temperature conversions before the slower
    EC read so they overlap.
    Also swap the upstream ds18 driver for the local in-tree copy.
    [ds18.c, main.c]
